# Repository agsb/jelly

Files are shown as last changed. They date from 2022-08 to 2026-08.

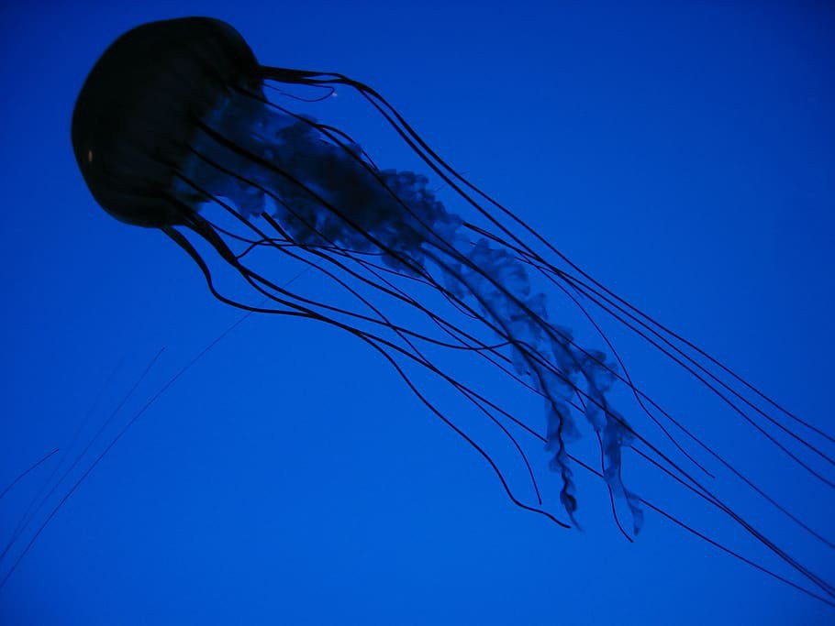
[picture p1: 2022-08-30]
jelly-blue.jpg

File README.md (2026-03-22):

-- THIS FILE IS A STUB ---

_01/05/2024 I'm on vacancy for refresh some ideas_

_22/03/2026 Review for make it_

# Jelly revision 2.0

Jelly is a concept, a alternative computer with a diferent paradigm, not for performance but for design.

Jelly is a minimal DIY 8-bit CPU made with CMOS chips, to perform computations using sequential access tapes.

## What is it ?

How make a new cpu without memory address, using only sequential access, for code, data and input/output ?

I want to learn about how old cpus are made by inside and understand about signals, gates, latches, pipelines, etc.

Jelly runs a minimal language, brainfunk, based in brainfuck, a minimal Turing-complete programming language with just eight commands. 

But Jelly includes few new commands to self.

Jelly uses sequential access to two ideal infinite tapes, first for code (aka ONE) and second for data (aka TWO). 

Any device could emulate a tape.

PS: 

The image is from https://en.freejpg.com.ar/free/info/100024149/jelly-fish-blue-water-background-sea-ocean-animal

I know that it will be slow.

Some notes are keeped at [ logbook ](https://github.com/agsb/jelly/blob/main/documents/LogBook.md).

There are a hackday log [ hackio ](https://hackaday.io/project/186689-jelly).

## Ideas

Jelly is not a common cpu.

- There is no general registers, just 3-state latches to keep the data bus safe. 

- There is no arithmetic logical unit (ALU), just a memory with a table of unary "math" results for increment, decrement and copy a byte, and also used to decode opcodes. Could include clear, shift right, shift left, negation.

- There is no comparator, just a flag for when a byte is zero or not.

- Uses Havard architeture, with code and data in diferent tapes.

- There is no memory address, just tapes that moves forward or backward.

- The standart input and output are instant stream devices, not tapes. 

And Jelly executes a esoteric language.

## Brainfunk

Jelly is really, a finite state machine, running by lookup tables and executing a extended version of language brainfuck, called brainfunk, which could have more 8 commands.

Jelly does a classical Read-Eval-Print Loop, or REPL, over bytes received from a code tape. For each byte, use a lookup table to translate into a opcode and execute actions. 

Not all bytes are opcodes and mapped as NOP, do nothing instruction, to catch those and just advance the code tape.

#### Table of OP-CODES
| opcode | ascii | action | code set | name |
| --- | --- | --- | --- | --- |
| 1 | \> | forward a tape one step | brainfuck | forward |
| 2 | \< | backward a tape one step | brainfuck | backward |
| 3 | \+ | increase byte at tape | brainfuck | increase |
| 4 | \- | decrease byte at tape | brainfuck | decrease |
| 5 | \. | output byte from tape | brainfuck | putchar |
| 6 | \, | input byte into tape | brainfuck | getchar |
| 7 | \[ | while loop  | brainfuck | while |
| 8 | \] | until loop  | brainfuck | until |
| 9 | \! | mark end of code | jelly | halt |
| 0 | \= | do nothing | jelly | noop |

- Any other ascii value is just translated as (0x0) noop.
- Opcodes 10, 11, 12, 13, 14, 15 reserved and could change.

## Jelly extensions

Jelly includes: (list can grow)

  - a noop, to do nothing, and moves code tape one step, forward or backward;
  
  - a eof, to end of code and halt, to be a complete Turing Machine;

### Jelly ideas

How the standart devices could be changed ? 

Maybe using the bytes at first two positions of data tape, to select which port to use, as input and output, as like in many microcontrolers ?

The math could include opcodes, for clear, shifts, negation, and reverse a byte.

## About loops

There are some brainfuck computers, but almost with the loop instructions _while_ and _until_ (\[ and \]) replaced by pre-compiled jumps. 

Jelly does not allow pre-compiler tricks, then need a logic to deal with loops.

The _while_ and _until_ loops are like the concepts of any programming language, but used together.

The _while_ ends the loop when the actual data byte is zero, then advances to pass the corresponding _until_. 

The _until_ repeats the loop while the actual data byte is not zero, then must go back after the corresponding _while_.

The loops can be nested, using a counter that increase for begins and decrease for again, finishing the loop when counter is zero. As a 8-bit circuit, the maximum nested loops is 255;

## Circuit Layout

How the Jelly circuit connects is explained in [circuit design](documents/CircuitDesign.md)

### Logic Loops

How loops are implemented in Jelly is explained in [logic loops](documents/LogicLoop.md)

## Main frame

Jelly will be a wirewrap circuit -- work in progress

## Work Bench

Jelly logic circuits needs some tests -- work in progress

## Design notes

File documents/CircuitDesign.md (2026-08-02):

--this file is still a stub--

# Circuit Design

In a processing unit, opcodes define what to make and microcode how to make. Opcode names an abstract action and microcode controls signals and flow of information to execute actions.

Jelly is a simple 8-bit digital circuit, all math, opcodes and microcodes are done by eeproms and latches. It haves a zero detector, a binary counter e some glue state logics, and LEDs many LEDS ! 

Jelly circuit include the interface for Device Control Circuit (DCC), that could be real tape or memory emulated.

Jelly uses 2kb space, address are A0-A10, data inputs are D0-D7, data outputs are Q0-Q7, and control lines are C0-C7. 

All chips used are CMOS, have /OE (output enable), CK (clock pulse) or CS (chip select), CR (clear latch) lines for select action. The eeproms have /WR (write enable) to VCC.

There are four 8-bit devices, a code tape, a data tape, a standart input and a standart output. For easy, a code_byte is read from code tape and data_byte is writed into or read from data tape. The standart devices are like streams and instantaneous.

The processing steps are based in lookup tables, defined by 16 (4-bits) operation codes - opcodes, each with 8 (3-bits) sequential steps - microcodes, in 4 (2-bits) modes, in total of 9 bits, 512 possibilities.

## Circuits

Rules:

- The chips are grouped by type, sequential numbers are used for identify;
- Use an internal and an external data bus;
- Minimize number of signals;
- Use pull-down to GND; 
- _"keep it simple, sweet"_;

### BOM

### States

02 eeproms, U1 and U2, are AT28C16, 150 ns (~ 6.7 MHz), 2k x 8-bits, and have /OE to GND, /CS to GND, /WR to VCC; U3 is reserved to an EEPROM future extention; Could be a AT28C64.

02 input latch, U4 and U5, 74HC574, 40 ns (< 20.0 MHz), octal D-Flip-Flop, 3-state, with clock (CK) and enable (/OE);

01 output latch, U6, 74HC574, 40 ns (< 20.0 MHz), octal D-Flip-Flop, 3-state, with clock (CK) and enable (/OE);

01 input-output switch, U7, is 74HC245, 40 ns (< 20.0 MHz), octal bi-diretional switch, 3-state, with direction (DIR) and enable (/OE);

01 binary counter, U8, 74HC393, (< 100 MHz), dual 4-bit binary counter, with clock (CK) and clear (CR);

### Glues

01 D-flip-flop, U10, is 74HC74, dual D-Type flip-flops, with clear and preset;

02 NAND gates, U15, U16, are 74HC00, 150 ns ( ~6.7 MHz ), quad 2-input NAND gate;

### Clock Circuit

One oscilator circuit with a 555, or 74HC00 and a crystal, gives a primary clock pulses less than 2.0 MHz; 

## Finite State Machine 

A binary up-counter 74HC393, U8, takes clock pulses from clock circuit, gives Q0-Q2 as A0-A3 into U1 (and U3), clear is CR3 and second counter _Q4-Q7 unused_;

A latch 74HC574, U4, takes D0-D7 from data bus, gives Q0-Q3 as A4-A7 into U1 (and U3), clock is CK4 and high nibble _Q4-Q7 unused_;

The eeprom(s) AT28C16, U1 (and U3), takes Q0-Q3 from U8 as A0-A3 and Q0-Q3 from U4 as A4-A7, U1 gives C0-C7 (and U3 gives C8-C15), as control lines to circuits, C0-C3 are T0-T3 and C4-C7 are M0-M3. 

This circuit is used to translate a byte as finite state machine (FSM) steps. 

It is used for opcode and microcode lookup, address A0-A2 are used for up 8 steps micro-code, A3-A6 for define 16 op-code, A7 selected by zero circuit detector, A8 selected by toggle a flip-flop as mode default or loop, _A9-A10 are reserved, not used_.

The lines D0-D7 (D8-D15) are used to select math operations and control signals inside and outside Jelly.

### Math Lookups and Decoder

One latch 74HC574, U5, takes D0-D7 from data bus, gives Q0-Q7 as A0-A7 into U2, clock is CK5;

One eeprom At28C16, U2, takes Q0-Q7 from U5 into A0-A7, takes C4-C6 from U1 into A8-A10, and gives Q0-Q7 into U6 as D0-D7; 

One latch 74HC574, U6, takes Q0-Q7 from U2 into D0-D7, giving Q0-Q7 as D0-D7 into data bus, output enable is /OE6, clock is CK6; 

The lookup table maps decode and unary operations as pages of 256 bytes, it could do more than increase and decrease. 

#### Table 1, Lookup M3 == 1
| name | M2 | M1 | M0 | action |
| ---- | ----- | ----- | ---- | --- |
| code | 0 | 0 | 0 | decode byte | 
| incr | 0 | 0 | 1 | increase |
| decr | 0 | 1 | 0 | decrease |
| copy | 0 | 1 | 1 | copy byte |
| | | | | |
| not  | 1 | 0 | 0 | one complement |
| lsh  | 1 | 0 | 1 | shift left 1 bit |
| rsh  | 1 | 1 | 0 | shift right 1 bit |
| copy | 1 | 1 | 1 | reverse bits |

Notes:
  - In _code_ all bytes are translated in valid opcodes range, 0 to 15, not defined symbols are mapped as noop; 
  - the code and copy are internal FSM operations, not allow from opcodes.
  - yes, was more 4 possible math: one complement, shift left, shift right, reverse. 

### External Devices

All devices are external and accessed by a 16 pin connector, with VCC, VSS, REQ, ACK, T0-T3 and D0-D7 data lines. 

( make it better !)

#### Table 2, Connector external
| line | Pin | Pin | line |
| --- | --- | --- | --- |
| ACK |  1 | 16 | VCC |
| D0  |  2 | 15 | T3 |
| D1  |  3 | 14 | T2 |
| D2  |  4 | 13 | T1 |
| D3  |  5 | 12 | T0 |
| D4  |  6 | 11 | D7 |
| D5  |  7 | 10 | D6 |
| GND |  8 |  9 | CLK |

The high nible T0-T1 selects devices, operations, comands and information for a controler at external word.

One input-output switch 74HC245, U7, takes Q0-Q7 from U6 into D0-D7, giving Q0-Q7 as D0-D7 into an external data bus, output enable is /OE7, direction is DR7; The Mode Operation is defined by 
T0-T3 from Finite State EEPROM U1

### Control Devices

The FSM eeproms gives Q0-Q7 (D8-Q15 with U3) for math and control lines. 

In the list of combinations used to control lines, state of devices and operations, the high nibble of U3.C4-C7 as T0-T3, vary from 0x1 to 0xD, leaving 0x0 to do nothing, and 0xE-0xF for select some extra states. 

Those extra states with some glue logics make needs just one eeprom as finite state machine. 

# ZZZZZ wip 

#### Table 3, Signals and states
| signal | combines | gives |
| -- | -- | -- |
| _used for control input/output transit_ | |
| U1.C0 | U4.CS | chip select line of U4 |
| U1.C1 | U5.CS | chip select line of U5 |
| U1.C2 | U6.OE | output enable line of U6 |
| U1.C3 | U7.OE | output enable line of U7 |
| _used for math unary operations and decode_ | |
| U1.C4 | U2.A8 | address line of U2 |
| U1.C5 | U2.A9 | address line of U2 |
| U1.C6 | U2.A10 | address line of U2 |
| U1.C7 | U6.CS | chip select line of U6 |
| _used to control devices_ | |
| U3.C0 | T0 | to connector device |
| U3.C1 | T1 | to connector device |
| U3.C2 | T2 | to connector device |
| U3.C3 | T3 | to connector device |
| _used to selects_ | | 
| U3.C4 | ??? | toggles MOVE line |
| U3.C5 | U1.A7 | toggles ZERO line |
| U3.C6 | U1.A8 | toggles MODE line |
| U3.C7 | ??? | clear D-flip-flop |
| halt | reduce AND clock | halt the clock |
| _used to detect zero value in data byte_ | | |
| zero | diode logic for D0 OR D1 OR D2 OR D3 OR D4 OR D5 OR D6 OR D7 | high when not zero |
| _extra connections toggles_ | | |
| | | |

Notes:

  - Zero detector could be done with diode logic OR for a Zero line.
  - Zero line is connected as U1.A7
  - Mode line is connected as U1.A8, 

--- need review ---

#### Table 4, Valid Controls
| byte | T3 | T2 | T1 | T0 || OE7 M3 | OE6 M2 | CS5 M1 | CS4 M0 | action |
| ---- | -- | -- | -- | --- |-- | --- | --- | --- | --- | --- |
| 0x00 | 0 | 0 | 0 | 0 || 0 | 0 | 0 | 0 | no action |
|  |  |  |  |  ||  |  |  |  |  |
| 0x60 | 0 | 1 | 1 | 0 || 0 | 0 | 0 | 0 | tape one, forward, no transfer |
| 0xA0 | 1 | 0 | 1 | 0 || 0 | 0 | 0 | 0 | tape two, forward, no transfer |
| 0x70 | 0 | 1 | 1 | 1 || 0 | 0 | 0 | 0 | tape one, backward, no transfer |
| 0xB0 | 1 | 0 | 1 | 1 || 0 | 0 | 0 | 0 | tape two, backward, no transfer |
|  |  |  |  |  ||  |  |  |  |  |
| 0x4C | 0 | 1 | 0 | 1 || 1 | 0 | 1 | 0 | tape one, write, U6 into U7 * |
| 0x8C | 1 | 0 | 0 | 1 || 1 | 0 | 1 | 0 | tape two, write, U6 into U7 |
| 0xCC | 1 | 1 | 0 | 1 || 1 | 0 | 1 | 0 | standard, write, U6 into U7 |
|  |  |  |  |  |  ||  |  |  |  |
| 0x5A | 0 | 1 | 0 | 0 || 1 | 1 | 0 | 0 | tape one, read, U7 into U5 |
| 0x9A | 1 | 0 | 0 | 0 || 1 | 1 | 0 | 0 | tape two, read, U7 into U5 |
| 0xDA | 1 | 1 | 0 | 0 || 1 | 1 | 0 | 0 | standard, read, U7 into U5 |
|  | |  |  |  |  ||  |  |  |  |
| 0x06 | 0 | 0 | 0 | 0 || 0 | 1 | 1 | 0 | none, none, U6 into U5 |
| 0x02 | 0 | 0 | 0 | 0 || 0 | 0 | 1 | 0 | none, none, clear U5, clear U3 **|
|  | |  |  |  |  |  ||  |  |  |
| 0x05 | 0 | 0 | 0 | 0 || 0 | 1 | 0 | 1 | none, none, U6 into U4, clear U3 |
| 0x01 | 0 | 0 | 0 | 0 || 0 | 0 | 0 | 1 | none, none, clear U4, clear U3 |
|  | |  |  |  ||  |  |  |  |  |

Notes:

- logics for /OE6 and /OE7 are inverted, just add a NOT later;  
- case 0x4C, tape one is code, no write allowed, never;
- case 0x02, set data latch to zero to be used as counter;
- case 0x05 and 0x01, also clear/reset U3;
- data bus D0-D7 have pull-down resistors for clear U4 and U5 when U6 and U7 are in 3-state.
- codes 0xFE, std forward, and 0xFF, std backward, do not exists and are used to control logic
- any other combination is invalid.

### Devices 

The lines U3.Q0-Q3 as T0-T3, output only and selects devices, operations, comands and information for a device controler at external word. The lines D0-D7 are bi-diretional, defaults to output. All lines are as pull-down and high actived. 

One bi-direcional switch, U7, 74HC245, uses D0-D7 as A0-A7 from internal data bus, uses B0-B7 as D0-D7 to external device bus, /OE is /OE7, DIR is DIR7.

An optional external, One dual 2:4 decoder, U9, 74HC139, uses T0-T3 as A0-A3 from U1, giving Y0-Y3 and Y4-Y7, for external controler, the /OE is GND.

Note: The /OE7 line is controled by not(T0 or T1) and direction DIR7 by T2; ****

#### Table 5, devices
| T3 | T2 | selects |
| --- | --- | --- |
| 0 | 0 | none, no device |  
| 0 | 1 | one, code tape | 
| 1 | 0 | two, data tape | 
| 1 | 1 | standart device |

#### Table 6, operations
| T1 | T0 | selects |
| --- | --- | --- |
| 0 | 0 | write into | 
| 0 | 1 | read from | 
| 1 | 0 | forward step| 
| 1 | 1 | backward step | 

Note: 
- order is (MSB) T3-T2-T1-T0 (LSB), (MSB) C3-C2-C1-C0 (LSB) 
- The standart input and output devices does no moves forward or backward.

### Glue Logics

The Zero detector circuit uses two quad dual OR gate, U13 and U14. Does (D0 OR D1 OR D2 OR D3 OR D4 OR D5 OR D6 OR D7). Wherever, U13 are all used and U14 gives Y3 as A8 into U1 and U2 of Jelly circuit, _spare one gate of U14_;

The Math selector circuit, uses one quad dual AND gates, U15. Does (M3 AND M0), (M3 AND M1), (M3 AND M2), gives Y1-Y3 as A8-A10 into U3, _spare one gate of U15_; 

The Toggle circuit, uses one quad dual AND gates, U16. Does (/M3 AND M0), (/M3 AND M1), (/M3 AND M2), gives Y0-Y1 as CLK1-CLK2 of U10, Y2 is reserved, _spare one gate of U16_;  

The U10 receive Y0-Y1 as CLK1-CLK2 from U16 and gives Q1 as A9 into U1 and U2, and Q2 to reverse direction circuit; 

The Reverse direction circuit gets Q2 from U10 and T2-T3 from U1, does ((Q2 AND T3) XOR T2) to DIR7 and T2 at connector;

All NOT() and XOR() are done by NAND ports;

## Lines

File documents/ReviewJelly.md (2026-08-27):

_this file is still a stub_

# Review of inside Jelly

## Talks

    Jelly talks to a Device. The device is the gateway to external world.
    Device have two internal infinite tapes, one of code and one of data, 
    and also a standart system for input and output.

## Goods

    1. Need a zero byte detector, for assert end loops

    2. Need a move selector flip-flop, forward or backward;

    3. Need a mode selector flip-flop, code or loop;

    4. Need a reset step, for resume step counter;

    5. Only one active device: none, code, data, stream

    6. Only one active action: read, write, forward, backward

    7. Math table for: decode, increase, decrease, copy, ( not, shift left, shift rigth ) 

    8. Need define a REQ/ACK handshake for Jelly and External IO 

    9. How sense ACK, when toggle REQ, trace external protocol

## Finite State Machines

_"FSMs are procedural, while planning is declarative."_

_"Informally, a category is just a collection of things, along with a particular relationship between these things"_

About MC14500 https://www.youtube.com/watch?v=ioL9cbNx0O8&t=2s

## Low frequency clock

For tests Jelly needs a low frequency oscillator as clock. 
A oscillator with one gate of 74HC14, a resistor between input and output 
pins and a capacitor between input and ground (GND) have frequency by 
_Hz = 1.2 * 10^6 / RC_ and use another gate to filter. 
Use R from 10k to 4M, use C from 1n to 100u;
( Using C = 100nF and R=10K, Hz ~ 1200 Hz, and C = 10uF and R=10K, Hz ~ 1.2 Hz, so on. )

## Concise Protocol

Two lines REQ and ACK. 

### Four-Phase

Four-Phase Handshake (RZ - Return-to-Zero): A very common and robust approach where control lines return to their initial state after each transaction. It involves four distinct steps:

    Request (Req) Active: Sender prepares data, then activates the Req line.
    Data Accepted: Receiver reads data, then activates the Ack line.
    Request Inactive: Sender detects Ack and brings Req low.
    Acknowledge Inactive: Receiver brings Ack low, returning the system to an idle state.

| REQ | ACK | results |
| -- | -- | -- |
|  0  |  0  | void |
|  1  |  0  | request |
|  1  |  1  | response |
|  0  |  1  | clear req |
|  0  |  0  | clear ack |

### Request-Acknowledge

The Jelly implementation is slightly diferent, Jelly and Device.

| SEQ | REQ | ACK | results |
| -- | -- | -- | -- |
| 0 |  0  |  0  | void state |
| 1 |  1  |  0  | Jelly prepares control and data, then active REQ |
| 2 |  1  |  0  | Device sense REQ, read controls |
| 3 |  1  |  1  | Device process data, then active ACK |
| 4 |  1  |  1  | Jelly sense ACK, process data |
| 5 |  0  |  1  | Jelly deactive REQ |
| 6 |  0  |  0  | Device sense REQ and deactive the ACK |
| 7 |  0  |  0  | return to void state |

Use REQ and ACK as a XOR to pause and continue the clock before it goes to 393/163 chip
    
| REQ | ACK | CLK | action |
| --- | --- | --- | --- |
| 0 | 0 | flow | device ready|
| 1 | 0 | stop | made a request to device|
| 1 | 1 | flow | device responds to request |
| 0 | 1 | stop | wait device ready for next |

## Components

U1  AT28C16 (A0-A10, D0-D7, /CE, /OE, /WE)

U2  AT28C16 (A0-A10, D0-D7, /CE, /OE, /WE)

U3  AT28C16 (A0-A10, D0-D7, /CE, /OE, /WE)

U4  74HC574 (D0-D7, Q0-Q7, CL, /OE), input code

U5  74HC574 (D0-D7, Q0-Q7, CL, /OE), input data

U6  74HC574 (D0-D7, Q0-Q7, CL, /OE), output data

U7  74HC245 (A0-A7, B0-B7, DR, /OE), bidirectional, code and data

U8  74HC393 (QA1, QB1, QC1, QD1, CLR1, /CLK1, QA2, QB2, QC2, QD2, CLR2, /CLK2)

U10 74HC74  (CLR1, CLK1, D1, Q1, /Q1, /PRE1, CLR2, CLK2, D2, Q2, /Q2, /PRE2)

U11 74HC74  (CLR1, CLK1, D1, Q1, /Q1, /PRE1, CLR2, CLK2, D2, Q2, /Q2, /PRE2)

U12 74HC00  (A1, A2, Y1, A3, A4, Y2, A5, A6, Y3, A7, A8, Y4) 

U13 74HC00  (A1, A2, Y1, A3, A4, Y2, A5, A6, Y3, A7, A8, Y4) 

## Buses

DB, data bus, (D0, D1, D2, D3, D4, D5, D6, D7), pull down with 10k resistors

CT, control bus, U1.(C0, C1, C2, C3, C4, C5, C6, C7), U3.(C8, C9, C10, C11, C12, C13, C14. C15)

IO, connector bus, (ACK, REQ, D0-D7, C8-C11, VCC, VSS)

## control

| C8 | C9 | device |
| -- | -- | -- |
| 0 | 0 | none | 
| 0 | 1 | code tape |
| 1 | 0 | data tape |
| 1 | 1 | std device |

| C10 | C11 | select |
| -- | -- | -- |
| 0 | 0 | read |
| 0 | 1 | write |
| 1 | 0 | forward |
| 1 | 1 | backward |

| C8 | C9 | C10 | C11 |  action |
| -- | -- | -- | -- | -- |
| 0  | 0  | 0  | 0  | nothing |
| 0  | 0  | 0  | 1  | nothing |
| 0  | 0  | 1  | 0  | nothing |
| 0  | 0  | 1  | 1  | nothing |
| | | | | 
| 1  | 1  | 1  | 0  | reserved |
| 1  | 1  | 1  | 1  | reserved |
    
## Tables 

### controls 
    
| origin | named | destin | note |
| -- | -- | -- | -- |
| U1.D0  | C0 | U4.CK | clock must be pulsed low to high |
| U1.D1  | C1 | U5.CK | clock must be pulsed low to high |
| U1.D2  | C2 | U6.CK | clock must be pulsed low to high |
| U1.D3  | C3 | U6.OE | enable output U6, tied to U7.DIR |
| U1.D4  | C4 | U7.OE | enable output U7 |
| U1.D5  | C5 |  | reserved |
| U1.D6  | C6 |  | reserved |
| U1.D7  | C7 |  | reserved |
|  |  |  |  |
| U3.D0 | C8 | Connector | device |
| U3.D1 | C9 | Connector | device |
| U3.D2 | C10 | Connector | select |
| U3.D3 | C11 | Connector | select |
| U3.D4 | C12 | Connector | request |
| U3.D5 | C13 |  | reserved |
| U3.D6 | C14 |  | reserved |
| U3.D7 | C15 |  | reserved |

Note: 

        U6.OE  goes high when input from Device and 
            goes low when output into Device

        U7.DIR tied to U6.OE, when U6.OE low U7.DIR is low, direction
            is from port B into port A, then port B must be connected 
            to DB and port A to Connector.

        C8 and C9 tied to U2.OE
        
#### Tables

https://github.com/agsb/jelly/blob/main/documents/ReviewJellyTable.md

### Math 

When C8 and C9 are low, C10, C11 and C12 are math functions. 
C8 and C9 must be pulldown, and connected to U2.OE (need some glue circuit)
Connect U3.D2(C10) to U2.A8, U3.D3(C11) to A2.A9, U3.D4(C12) to U2.A10 to select math function

### Clock

1. CLOCK -> U8(D1)

### Code

1. DB(D0-D7) -> U4(D0-D7)

2. U8(QA1, QB1, QC1, QD1) -> U1(A0-A3), 16 steps or stages

3. U4(Q0-Q3) -> U1(A4-A7), 16 opcodes, (A8, A9, A10) 8 modes

4. U4(Q4-Q7) -> Not used

5. U1(D0-D7) -> CT(C0-C7)

### Data Internal 

6. DB(D0-D7) -> U5(D0-D7)

7. U5(Q0-Q7) -> U2(A0-A7)

8. CT(C10,C11,C12) -> U2(A8,A9), 8 math operations: none, INC, DEC, COPY, (NOT, SHL, SHR, 

9. CT(C8,C9) --> U2.OE

10. U2(D0-D7) -> U6(D0-D7)

11. U6(Q0-Q7) -> DB(D0-D7)

## Data External Output

11. DB(D0-D7) -> U7(B0-B7)

12. U7(B0-B7) -> U7(A0-A7), internal

13. U7(A0-A7) -> IO(D0-D7)

## Data External Input

14. IO(D0-D7) -> U7(A0-A7)

15. U7(A0-A7) -> U7(B0-B7), internal

16. U7(B0-B7) -> DB(D0-D7)

## Problems

When detect a ACK, it could be from a:

* read a byte from code tape
* write a byte into code tape ---- ERROR
* read a byte from data tape
* write a byte into data tape
* read a byte from stds 
* write a byte into stds
* move code tape forward
* move code tape backward
* move data tape forward
* move data tape backward

    On read cases, the byte must be load somewhere.
## Notes

The data bus D0-D7 is pull down 10k resistors. 
    
The addr bus A0-A7 is pull down 10k resistors. 

Using U4.CL, U5.CL and U6.CL tied to OE, pulsed to high do load the latch. 

Ever when U6.OE is low U7.DIR must goes to outside, 
        then port B is connected to DB and port A is connected to CON.

An 74HC14 serves the clock to 74HC393 steps.

The (T0 T1) the 0/0 is a internal, else is a external and tied REQ

using ANOTHER AT28C16 allow more controls.

## References

https://web.stanford.edu/class/archive/cs/cs103/cs103.1132/lectures/19/Small19.pdf

https://bailleux.net/pub/ob-project-gray1.pdf

https://www.gamedevs.org/uploads/three-states-plan-ai-of-fear.pdf

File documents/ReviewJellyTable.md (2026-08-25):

__This file is still a stub__

# Control Table

The lines from U1 and U3 gives the control signals to U4, U5, U6, U7 and to Connector to Device.

Notes:

    U6.OE6 tied U7.DIR
    When U6 is low active, then U7 direction is from port B to port A, byte into Connector.
    When U6 is high inactive, then U7 direction is from port A to port B, byte from Connector.

Using PinUnit for easy
    
| C0  | C1  | C2  | C3  | C4  | C5  | C6  | C7  | C8  | C9  | C10 | C11 | C12 | C13 | C14 | C15 | results | 
| --- | --- | --- | --- | --- | --- | --- | --- | --- | --- | --- | --- | --- | --- | --- | --- | --- |
| CK4 | CK5 | CK6 | OE6 | OE7 |  0  | 0 | 0 | DEV0 | DEV1 | SEL0 | SEL1 | REQ |  0 | 0 | 0 | 0 |  | 
| | | | | | | | | | | | | | | | |  |
| 0 | 0 | 0 | 0 | 0 | 0 | 0 | 0 | 0 | 0 | 0 | 0 | 0 | 0 | 0 | 0 |  | 
| 1 | 0 | 0 | 0 | 0 | 0 | 0 | 0 | 0 | 0 | 0 | 0 | 0 | 0 | 0 | 0 | load db byte to latch U4 | 
| 0 | 1 | 0 | 0 | 0 | 0 | 0 | 0 | 0 | 0 | 0 | 0 | 0 | 0 | 0 | 0 | load db byte to latch U5 | 
| 0 | 0 | 1 | 0 | 0 | 0 | 0 | 0 | 0 | 0 | 0 | 0 | 0 | 0 | 0 | 0 | load db byte to latch U6 | 
| 0 | 0 | 0 | 1 | 0 | 0 | 0 | 0 | 0 | 0 | 0 | 0 | 0 | 0 | 0 | 0 |  | 
| | | | | | | | | | | | | | | | |  |
| | | | | | | | | | | | | | | | |  |
| | | | | | | | | | | | | | | | |  |

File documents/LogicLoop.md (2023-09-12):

  
( this file is still a stub ) 

# Logic Loop

All Jelly opcodes are easy implemented except loops. 

A interpreter of brainfunk, in pseudo-code, _left not optimized, sure not optimized, did I said it is not optimized ?_ :

         // Notes:
         // getch(), putch() e halt() are external
         // for easy the tapes are mapped as sequential memory
         
         char * code_ptr = POINTER_TO_CODE;
         char * data_ptr = POINTER_TO_DATA;
         
         int mode = 0; // the page
         int move = 0; // the direction
         int data_byte = 0;
         int code_byte = 0;
         
         do {
             code_byte = *code_ptr;
             
             // end of loop ?
             if (code_byte == '\[' and data_byte == 0) mode = 1, move = 0;
             // not end of loop ?
             if (code_byte == '\]' and data_byte != 0) mode = 1, move = 1;
            
             if (mode == 1) { 
                 data_byte = 0; // used as counter
                 do {
                     code_byte = *code_ptr;
                     if (code_byte == '\[') data_byte++;
                     if (code_byte == '\]') data_byte--;
                     if (move == 0) code_ptr++;
                     if (move == 1) code_ptr--;
                 } while (data_byte != 0);
                 // 
                 if (move == 1) code_ptr++, code_ptr++;
                 mode = 0;
                 move = 0;
                 data_byte = *data_ptr;
                 continue;
             }
             
             // mode 0 == 0, all other opcodes: < > . , + -
             
             if (code_byte == '+') { data_byte = *data_ptr; data_byte++; *data_ptr = data_byte; }
             if (code_byte == '-') { data_byte = *data_ptr; data_byte--; *data_ptr = data_byte; }
             if (code_byte == '>') { data_ptr++; }
             if (code_byte == '<') { data_ptr--; }
             if (code_byte == '.') { data_byte = *data_ptr; putch(data_byte); }
             if (code_byte == ',') { data_byte = getch(); *data_ptr = data_byte; }

             if (code_byte == '!') { halt(); }
             code_ptr++;
           } while (1);

Notes:

For easy, the \[ is called _while_ and the \] is called _until_
                    
When grouping the code in dependence of state of loop, gives two modes, the normal mode does all opcodes but _while_ and _until_. Those are executed by the loop mode, described as: 

When a _while_ occurs and the data byte is zero, it's the end of the loop, so it must step **forward** to find the corresponding _until_, and return to mode normal;

When a _until_ occurs and the data byte is not zero, then it is not the end of the loop, so it must step **backward** to find the corresponding _while_, and return to mode normal;

Since no data bytes are read in loop mode, the circuit U5-U2-U6 is used as a counter for up to 255 nested loops;

### Actions 

the actions from pseudo-code are:

- move code tape forward
- move code tape backward
- move data tape forward
- move data tape backward
- read from data tape into data latch
- increase data latch
- decrease data latch
- write from data latch into data tape
- read from code tape into data latch
- decode data latch
- copy from data latch to code latch
- clear data latch
- read from standart input device into data latch
- write from data latch into standart output device
- test if a data latch is zero

Those actions must be done by combination of control lines, selects which chips is active at a clock instant.

## How To

How implement the loop opcodes _while_ and _until_ , keep me in a round-robin by months without a feasible solution.

A solution is a true table of five state lines, while, again, zero, mode, move and two result toggle switches S1 and S2, that controls which mode and reverse movement.

the solution was make true-table for lines and states.

- _while_ is a condition set high when code_byte is [

- _until_ is a condition set high when code_byte is ]

- _zero_ is a condition set low when data_byte is zero. 

- _mode_ is condition a address line for eeproms U1 and U3.

- _move_ is condition a address line for reverse movement.

- switch mode is the next state of _mode_.

- switch move is the next state of _move_.

## True Table

   | case | zero | mode | move | _while_ | _again_ | _switch mode_ | _switch move_ | results |
   | --- | --- | --- | --- | --- | --- | --- | --- | --- | 
   | 1 | 0/1 | 0 | 0 | 0 | 0 | 0 | 0 | default |
   | 2 | 0 | 0 | 0 | 1 | 0 | 1 | 0 | set mode,  |
   | 3 | 1 | 0 | 0 | 0 | 1 | 1 | 1 | set mode, set move |
   | 4 | 0 | 1 | 0/1 | 0 | 0 | 0 | 0 | set mode, set move | 
   | 5 | 1 | 1 | 0/1 | 1 | 0 | 1 | 0/1 | increase counter, set mode, set move |
   | 6 | 1 | 1 | 0/1 | 0 | 1 | 1 | 0/1 | decrease counter, set mode, set move |

The paging is controled just from five conditions, and _switch mode_ and _switch move_ could do clock lines to D-flip-flops.

For simplify, when mode is normal (0), move is always for forward (0) and when mode is loop (1), the state of _while_ and _until_ does changes the counter;

## Circuits

Jelly have 16 opcodes of 8 microcodes, then a code page uses 128 bytes.

I tried to implement the truth table in three ways: 1. With only one FSM eeprom and complex multiplex circuits for logics; 2. With 4 pages at second FSM eeprom and external circuits; and 3. With 6 pages at second FSM eeprom and few external circuits;

### one eeprom and many circuits

### two eeproms and less circuits

### two eeproms and minimal logic circuits

## Considerations

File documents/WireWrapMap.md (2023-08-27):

# WireWrapMap

-- This file is still a stub --

## Chips used in Jelly

  - U1 AT28C16 [at28c16](https://github.com/agsb/jelly/assets/14941647/0e6a42e7-9d13-4c5b-8078-834cc9717078)
  - U2 AT28C16 [at28c16](https://github.com/agsb/jelly/assets/14941647/0e6a42e7-9d13-4c5b-8078-834cc9717078)
  - U3 AT28C26 [at28c16](https://github.com/agsb/jelly/assets/14941647/0e6a42e7-9d13-4c5b-8078-834cc9717078)
  - U4 74HC574 [74hc574](https://github.com/agsb/jelly/assets/14941647/389d5967-7fb1-4645-8b06-98f8ca35686f)
  - U5 74HC574 [74hc574](https://github.com/agsb/jelly/assets/14941647/389d5967-7fb1-4645-8b06-98f8ca35686f)
  - U6 74HC574 [74hc574](https://github.com/agsb/jelly/assets/14941647/389d5967-7fb1-4645-8b06-98f8ca35686f)
  - U7 74HC245 [74hc245](https://github.com/agsb/jelly/assets/14941647/2990746c-01e9-4c97-b71f-3ceca05f751b)
  - U8 74HC393 [74hc393](https://github.com/agsb/jelly/assets/14941647/131a82d1-9269-4ded-93cc-4d0f6053b101)
  - U9  74HC74 [74hc74](https://github.com/agsb/jelly/assets/14941647/7b43e177-1a82-49fd-ad0a-cf376e5011dd)
  - U10 74HC00 [74hc00](https://github.com/agsb/jelly/assets/14941647/2f70cb16-b870-4e8b-bac9-e86a2bcbbb6e)
  - C1 to C10, capacitor 100nF
  - C11 to C14, capacitor 4.7uF 

## Connections for WireWrap

  - POWER, all VCC connect U1.24, U2.24, U3.24, U4.20, U5.20, U6.20, U7.20, U8.14, U9.14, U10.14
  - GROUND, all GND connect U1.12, U2.12, U3.12, U4.10, U5.10, U6.10, U7.10, U8.7, U9.7, U10.7
  - CAPS, (U1.24-C1.1, C1.2-U1.12) for U1 C1 to U10 C10

#### 
	// master FSM eeprom
	U1.01-ZERO
	U1.02-U4.16
	U1.03-U4.17
	U1.04-U4.18
	U1.05-U4.19
	U1.06-U8.11
	U1.07-U8.10
	U1.08-U8.09
	U1.09-U4.11	// CLK
	U1.10-U5.11	// CLK
	U1.11-U6.11	// CLK
	U1.12-GND
	U1.13-U6.01	// /OE
	U1.14-U7.01	// /OE
	U1.15-U2.A8
	U1.16-U2.A9
	U1.17-U2.A10
	U1.18-GND
	U1.19-GND	// A10
	U1.20-GND
	U1.21-VCC
	U1.22-A9 ????
	U1.23-A8 ????
	U1.24-VCC

	// master Math/Decode eeprom
	U2.01-U5.12
	U2.02-U5.13
	U2.03-U5.14
	U2.04-U5.15
	U2.05-U5.16
	U2.06-U5.17
	U2.07-U5.18
	U2.08-U5.19
	U2.09-U6.02
	U2.10-U6.03
	U2.11-U6.04
	U2.12-GND
	U2.13-U6.05
	U2.14-U6.06
	U2.15-U6.07
	U2.16-U6.08
	U2.17-U6.09
	U2.18-GND
	U2.19-A10 ???
	U2.20-GND
	U2.21-VCC
	U2.22-A9 ???
	U2.23-A8 ???
	U2.24-VCC

	// control FSM eeprom
	U3.01-ZERO
	U3.02-U1.02
	U3.03-U1.03
	U3.04-U1.04
	U3.05-U1.05
	U3.06-U1.06
	U3.07-U1.07
	U3.08-U1.08
	U3.09-
	U3.10-
	U3.11-
	U3.12-GND
	U3.13-
	U3.14-
	U3.15-
	U3.16-
	U3.17-
	U3.18-GND
	U3.19-U1.19
	U3.20-GND
	U3.21-VCC
	U3.22-U1.22
	U3.23-U1.23
	U3.24-VCC
	
	// code byte latch, only low nibble used
	U4.01-GND
	U4.02-U5.02
	U4.03-U5.03
	U4.04-U5.04
	U4.05-U5.05
	U4.06-U5.06
	U4.07-U5.07
	U4.08-U5.08
	U4.09-U5.09
	U4.10-GND
	U4.11-CLK ????
	U4.12-NC
	U4.13-NC
	U4.14-NC
	U4.15-NC
	U4.16-U1.02
	U4.17-U1.03
	U4.18-U1.04
	U4.19-U1.05
	U4.20-VCC

	// data byte latch, input into Math
	U5.01-GND
	U5.02-U6.19
	U5.03-U6.18
	U5.04-U6.17
	U5.05-U6.16
	U5.06-U6.15
	U5.07-U6.14
	U5.08-U6.13
	U5.09-U6.12
	U5.10-GND
	U5.11-CLK ????
	U5.12-U2.01
	U5.13-U2.02
	U5.14-U2.03
	U5.15-U2.04
	U5.16-U2.05
	U5.17-U2.06
	U5.18-U2.07
	U5.19-U2.08
	U5.20-VCC

	// data byte latch, output from Math
	U6.01-????
	U6.02-U2.19
	U6.03-U2.18
	U6.04-U2.17
	U6.05-U2.16
	U6.06-U2.15
	U6.07-U2.14
	U6.08-U2.13
	U6.09-U2.12
	U6.10-GND
	U6.11-CLK ????
	U6.12-U7.09
	U6.13-U7.08
	U6.14-U7.07
	U6.15-U7.06
	U6.16-U7.05
	U6.17-U7.04
	U6.18-U7.03
	U6.19-U7.02
	U6.20-VCC

	// input output switch
	U7.01-DIR ???
	U7.02-U6.19
	U7.03-U6.18
	U7.04-U6.17
	U7.05-U6.16
	U7.06-U6.15
	U7.07-U6.14
	U7.08-U6.13
	U7.09-U6.12
	U7.10-GND
	U7.11-CONN9
	U7.12-CONN8
	U7.13-CONN6
	U7.14-CONN5
	U7.15-CONN4
	U7.16-CONN3
	U7.17-CONN2
	U7.18-CONN1
	U7.19-OE ????
	U7.20-VCC

	U8.12-U8.08	// counts 0 to 7 and resets.
	U8.13-?????	// whats comes to clear it

	NC-U8.01
	NC-U8.02
	NC-U8.03
	NC-U8.04
	NC-U8.05
	NC-U8.06

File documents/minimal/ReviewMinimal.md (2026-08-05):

_this file is still a stub_

# review of inside a really minimal Jelly

## goods

    1. Need a zero byte detector, for assert end loops

    2. Need a move selector flip-flop, forward or backward;

    3. Need a mode selector flip-flop, code or loop;

    4. Need a reset step, for resume step counter;

    5. Only one active device: none, code, data, stream

    6. Only one active action: read, write, forward, backward

    7. Math table for: decode, increase, decrease, copy, zero(?) 

    8. Need define a REQ/ACK handshake for Jelly and External IO, how sense ACK, when toggle REQ, trace external protocol

## Finite State Machines

_"FSMs are procedural, while planning is declarative."_

_"Informally, a category is just a collection of things, along with a particular relationship between these things"_

## low frequency clock

For tests Jelly needs a low frequency oscilator as clock. A oscilator with one gate of 74HC14, a resistor between input and output pins and a capacitor between input and ground (GND) have frequency by _Hz = 1.2 * 10^6 / RC_ and use another gate to filter. 
Use R from 10k to 4M, use C from 1n to 100u;
( Using C = 100nF and R=10K, Hz ~ 1200 Hz, and C = 10uF and R=10K, Hz ~ 1.2 Hz, so on. )

## Consise Protocol

Two lines REQ and ACK. 

### Four-Phase

Four-Phase Handshake (RZ - Return-to-Zero): A very common and robust approach where control lines return to their initial state after each transaction. It involves four distinct steps:

    Request (Req) Active: Sender prepares data, then activates the Req line.
    Data Accepted: Receiver reads data, then activates the Ack line.
    Request Inactive: Sender detects Ack and brings Req low.
    Acknowledge Inactive: Receiver brings Ack low, returning the system to an idle state.

| REQ | ACK | results |
|  0  |  0  | void |
|  1  |  0  | request |
|  1  |  1  | response |
|  0  |  1  | clear req |
|  0  |  0  | clear ack |

### Request-Acknowledge

When a request is made with (T0 T1 T2 T3):

    1. Place a request 
    2. Down ACK
    3. Wait REQ Down
    4. Resume request
    5. Up ACK
    6. wait REQ UP

## Components

U1  AT28C16 or AT28C32 (A0-A12, D0-D7, /CE, /OE, /WE)

U2  AT28C16 or AT28C32 (A0-A12, D0-D7, /CE, /OE, /WE)

U3  AT28C16 or AT28C32 (A0-A12, D0-D7, /CE, /OE, /WE) ***

U4  74HC574 (D0-D7, Q0-Q7, CL, /OE), input code

U5  74HC574 (D0-D7, Q0-Q7, CL, /OE), input data

U6  74HC574 (D0-D7, Q0-Q7, CL, /OE), output data

U7  74HC245 (A0-A7, B0-B7, DR, /OE), bidiretional, code and data

U8  74HC393 (QA1, QB1, QC1, QD1, CLR1, /CLK1, QA2, QB2, QC2, QD2, CLR2, /CLK2)

U10 74HC74  (CLR1, CLK1, D1, Q1, /Q1, /PRE1, CLR2, CLK2, D2, Q2, /Q2, /PRE2)

U11 74HC00  (A1, A2, Y1, A3, A4, Y2, A5, A6, Y3, A7, A8, Y4) 

## Buses

DB, data bus, (D0, D1, D2, D3, D4, D5, D6, D7)

CT, control bus, (C0, C1, C2, C3, C4, C5, C6, C7)

IO, conector bus, (CLK, ACK, D0-D7, T0-T3)

## IO Control

    | T3 | T2 | device OR |
    | 0 | 0 | none | 
    | 0 | 1 | code tape |
    | 1 | 0 | data tape |
    | 1 | 1 | std device |

    | T1 | T0 | select OR |
    | 0 | 0 | read |
    | 0 | 1 | write |
    | 1 | 0 | forward |
    | 1 | 1 | backward |

    | T3 | T2 | T1 | T0 | not used |
    | 0  | 0  | 0  | 0  | nothing |
    | 0  | 0  | 0  | 1  | nothing |
    | 0  | 0  | 1  | 0  | nothing |
    | 0  | 0  | 1  | 1  | nothing |
    | | | | | 
    | 1  | 1  | 1  | 0  | clear ACK |
    | 1  | 1  | 1  | 1  | nothing |

## Tables 

### controls 
    
U1(D0-D7) to (U4.CE, U5.CE, U6.CE, U6.OE, U7.DIR, U7.OE, X6, X7). Note that U4.OE and U5.OE are always low, because U4-U1 and U5-U2 are closed circuits.

### functions

U3(D0-D7) to (M0, M1, M2, M3, T0, T1, T2, T3)

### Clock

1. CLOCK -> U8(D1)

### Code

1. U8(QA1, QB1, QC1) -> U1(A0, A1, A2), 8 steps or stages

1. DB(D0-D7) -> U4(D0-D7)

2. U4(Q0-Q4) -> U1(A3-A7), 32 opcodes, (A8, A9, A10) 8 modes

3. U1(D0-D7) -> CT(C0-C7)

### Data Internal 

4. DB(D0-D7) -> U5(D0-D7)

5. U5(Q0-Q7) -> U2(A0-A7)

6. CT(C0,C2,C3) -> U2(A8,A9,A10)

6. U2(D0-D7) -> U6(D0-D7)

7. U6(Q0-Q7) -> DB(D0-D7)

## Data External 

10. DB(D0-D7) -> U7(A0-A7)

11. U7(B0-B7) -> IO(D0-D7)

10. IO(D0-D7) -> U7(B0-B7)

11. U7(A0-A7) -> DB(D0-D7)

## Notes

    The data bus D0-D7 is pull down 10k resistors. 
    Using U4.CL or U5.CL pulse with U6.OE high and U7.OE high,
    loads zero. 

    An 74HC14 serves the clock to 74HC393 steps.

## References

https://web.stanford.edu/class/archive/cs/cs103/cs103.1132/lectures/19/Small19.pdf

https://bailleux.net/pub/ob-project-gray1.pdf

https://www.gamedevs.org/uploads/three-states-plan-ai-of-fear.pdf

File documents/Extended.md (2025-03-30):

# Extended

An Extended Brainfunk was proposed [1] to simulating digital conditions 
for complex systems. 

## code 

A virtual infinite tape with two heads (0 and 1), 
one head is a program cursor and other is a data cursor, and keep same 
operations but change . and , to exchange bytes between heads and two 
more { and } for move the other head backward and forward.

```
    < head0 = head0 - 1
    > head0 = head0 + 1
    { head1 = head1 - 1
    } head1 = head1 + 1
    - tape[head0] = tape[head0] - 1
    + tape[head0] = tape[head0] + 1
    . tape[head1] = tape[head0]
    , tape[head0] = tape[head1]
    [ if (tape[head0] == 0): jump forwards to matching ] command.
    ] if (tape[head0] != 0): jump backwards to matching [ command.

```

## extras

## references

[1] "Computational Life: How Well-formed, Self-replicating Programs 
Emerge from Simple Interaction", 
Blaise Agüera y Arcas†, Jyrki Alakuijala†, James Evans‡,
Ben Laurie†, Alexander Mordvintsev†, Eyvind Niklasson†,
Ettore Randazzo†, Luca Versari†,
†Google, Paradigms of Intelligence Team and ‡The University of Chicago
{blaisea, jyrki, benl, moralex, eyvind, etr, veluca}@google.com
jevans@uchicago.ed

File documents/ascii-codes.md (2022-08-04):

--- this file is a stub ---

| Dec 	| Hex 	| Binary 	| HTML 	| Char 	| Description |
| --- | --- | --- | --- | --- | --- |
| 0 	| 00 	| 00000000 	| &#0; 	| NUL 	| Null |
| 1 	| 01 	| 00000001 	| &#1; 	| SOH 	| Start of Header |
| 2 	| 02 	| 00000010 	| &#2; 	| STX 	| Start of Text |
| 3 	| 03 	| 00000011 	| &#3; 	| ETX 	| End of Text |
| 4 	| 04 	| 00000100 	| &#4; 	| EOT 	| End of Transmission |
| 5 	| 05 	| 00000101 	| &#5; 	| ENQ 	| Enquiry |
| 6 	| 06 	| 00000110 	| &#6; 	| ACK 	| Acknowledge |
| 7 	| 07 	| 00000111 	| &#7; 	| BEL 	| Bell |
| 8 	| 08 	| 00001000 	| &#8; 	| BS 	| Backspace |
| 9 	| 09 	| 00001001 	| &#9; 	| HT 	| Horizontal Tab |
| 10 	| 0A 	| 00001010 	| &#10; 	| LF 	| Line Feed |
| 11 	| 0B 	| 00001011 	| &#11; 	| VT 	| Vertical Tab |
| 12 	| 0C 	| 00001100 	| &#12; 	| FF 	| Form Feed |
| 13 	| 0D 	| 00001101 	| &#13; 	| CR 	| Carriage Return |
| 14 	| 0E 	| 00001110 	| &#14; 	| SO 	| Shift Out |
| 15 	| 0F 	| 00001111 	| &#15; 	| SI 	| Shift In |

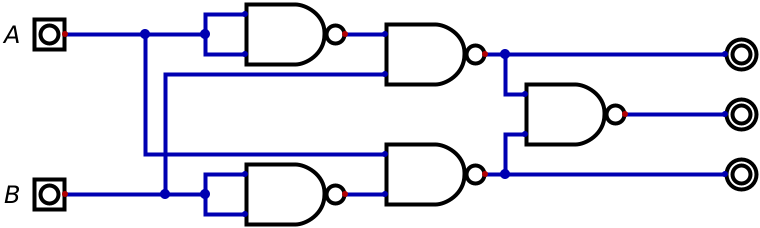
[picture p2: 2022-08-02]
jellys/extras/2bit-comparator.png

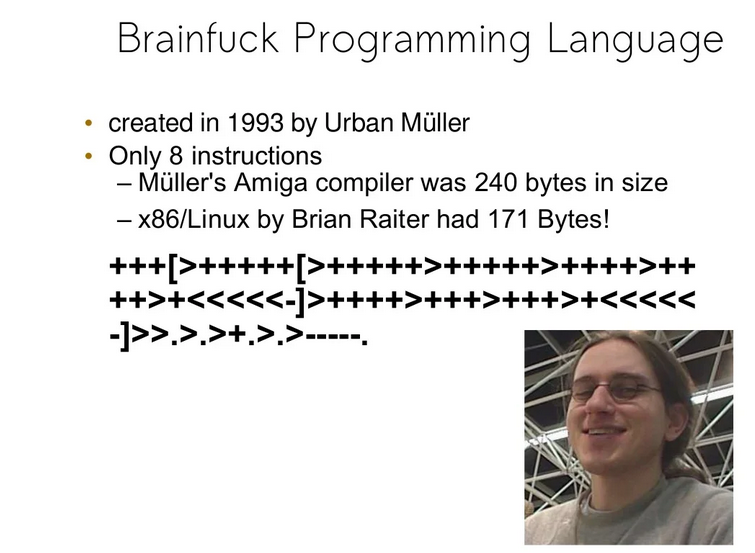
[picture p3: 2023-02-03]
documents/brainfuck-urban-muller.png

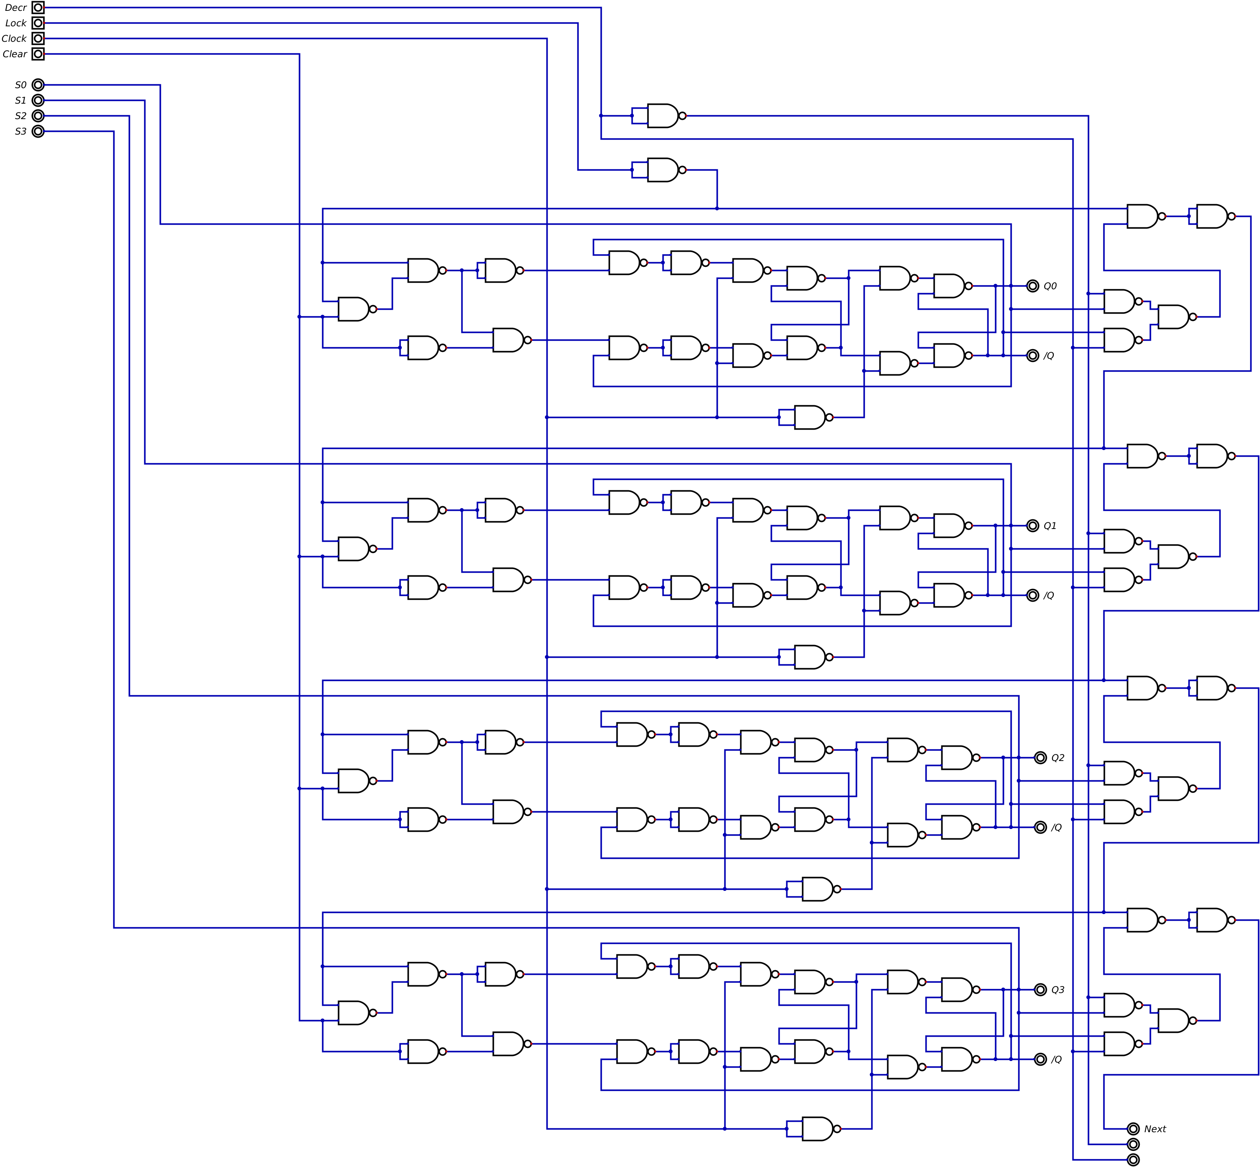
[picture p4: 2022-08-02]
jellys/extras/jk-counter-clr-inc-dec-4bits.png

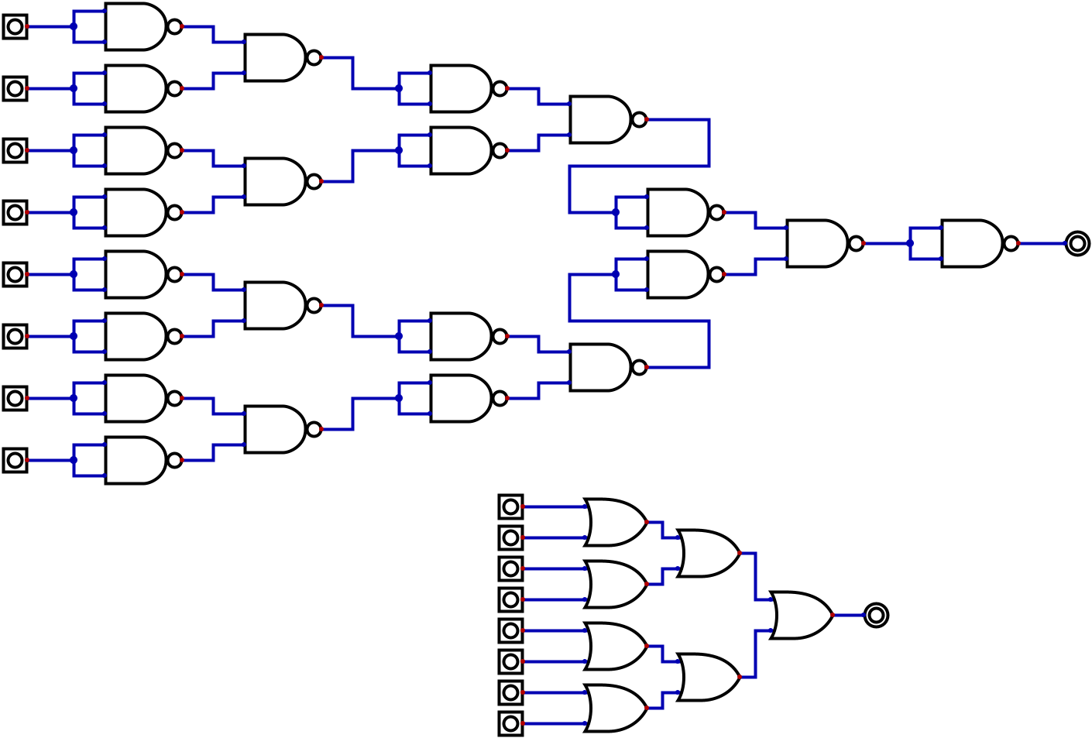
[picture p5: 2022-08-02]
jellys/extras/comparator-zero-8bits.png

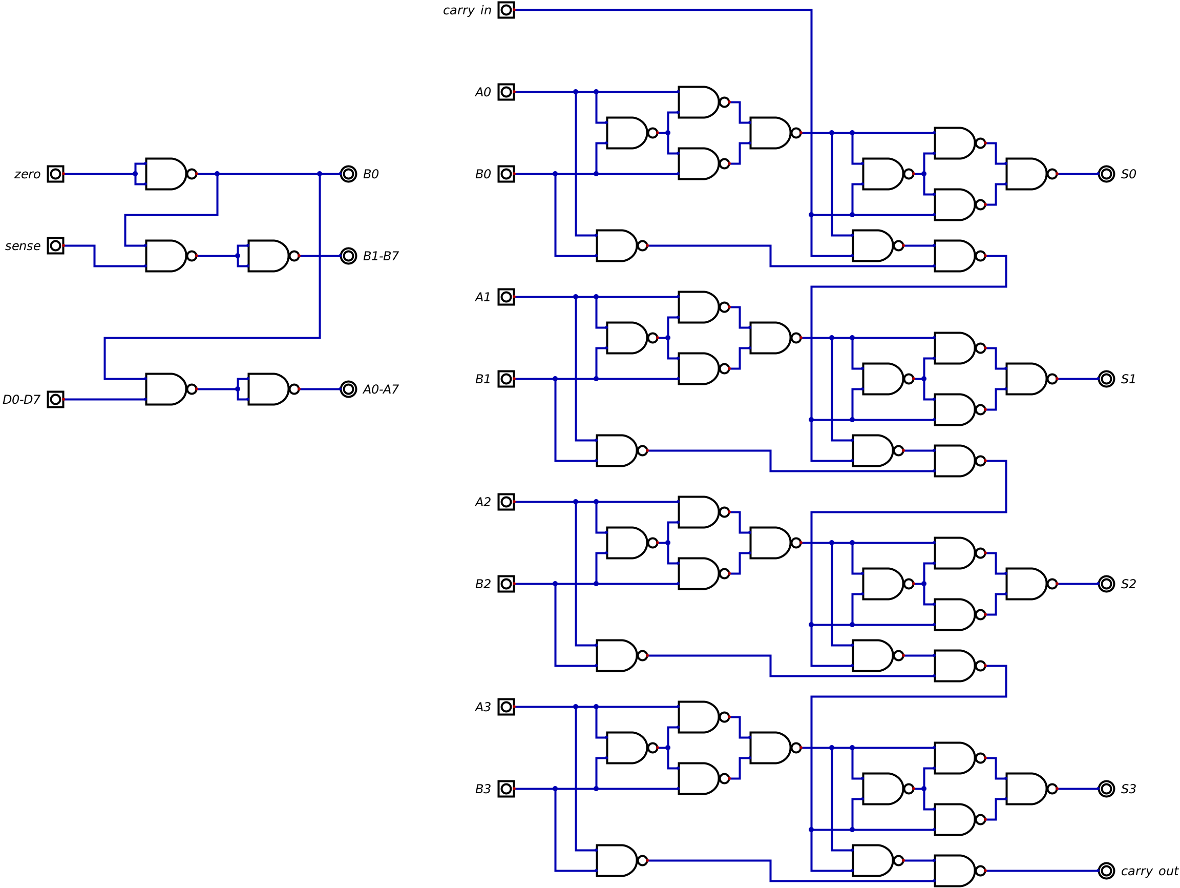
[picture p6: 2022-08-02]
jellys/extras/d-adder-inc-dec-4bits.png

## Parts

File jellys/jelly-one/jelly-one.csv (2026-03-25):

Source: | /home/agsb/Projects/jelly-one/jelly-one.kicad_sch
Date: | qui 04 ago 2022 15:55:19
Tool: | Eeschema 6.0.4-6f826c9f35~116~ubuntu18.04.1
Generator: | /usr/share/kicad/plugins/bom_csv_grouped_by_value.py
Component Count: | 10
Individual Components:
Item | Qty | Reference(s) | Value | LibPart | Footprint | Datasheet
 |  | U1 | 74AHC374 | 74xx:74AHC374 |  | https://assets.nexperia.com/documents/data-sheet/74AHC_AHCT374.pdf
 |  | U2 | 74LS32 | 74xx:74LS32 |  | http://www.ti.com/lit/gpn/sn74LS32
 |  | U3 | 74LS32 | 74xx:74LS32 |  | http://www.ti.com/lit/gpn/sn74LS32
 |  | U4 | 74LS32 | 74xx:74LS32 |  | http://www.ti.com/lit/gpn/sn74LS32
 |  | U5 | 74LS393 | 74xx:74LS393 |  | 74xx\74LS393.pdf
 |  | U6 | 74LS393 | 74xx:74LS393 |  | 74xx\74LS393.pdf
 |  | U7 | 74LS08 | 74xx:74LS08 |  | http://www.ti.com/lit/gpn/sn74LS08
 |  | U8 | 74LS32 | 74xx:74LS32 |  | http://www.ti.com/lit/gpn/sn74LS32
 |  | U9 | 74LS32 | 74xx:74LS32 |  | http://www.ti.com/lit/gpn/sn74LS32
 |  | U10 | 28C256 | Memory_EEPROM:28C256 |  | http://ww1.microchip.com/downloads/en/DeviceDoc/doc0006.pdf
Collated Components:
Item | Qty | Reference(s) | Value | LibPart | Footprint | Datasheet
1 | 1 | U1 | 74AHC374 | 74xx:74AHC374 |  | https://assets.nexperia.com/documents/data-sheet/74AHC_AHCT374.pdf
2 | 5 | U2, U3, U4, U8, U9 | 74LS32 | 74xx:74LS32 |  | http://www.ti.com/lit/gpn/sn74LS32
3 | 2 | U5, U6 | 74LS393 | 74xx:74LS393 |  | 74xx\74LS393.pdf
4 | 1 | U7 | 74LS08 | 74xx:74LS08 |  | http://www.ti.com/lit/gpn/sn74LS08
5 | 1 | U10 | 28C256 | Memory_EEPROM:28C256 |  | http://ww1.microchip.com/downloads/en/DeviceDoc/doc0006.pdf

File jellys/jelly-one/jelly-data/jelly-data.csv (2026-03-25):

Source: | /home/agsb/Projects/jelly-one/jelly-data/jelly-data.kicad_sch
Date: | qui 04 ago 2022 15:58:50
Tool: | Eeschema 6.0.4-6f826c9f35~116~ubuntu18.04.1
Generator: | /usr/share/kicad/plugins/bom_csv_grouped_by_value.py
Component Count: | 6
Individual Components:
Item | Qty | Reference(s) | Value | LibPart | Footprint | Datasheet
 |  | J1 | Conn_01x16_Female | Connector:Conn_01x16_Female |  | ~
 |  | U1 | 74AHC374 | 74xx:74AHC374 |  | https://assets.nexperia.com/documents/data-sheet/74AHC_AHCT374.pdf
 |  | U2 | 74AHC374 | 74xx:74AHC374 |  | https://assets.nexperia.com/documents/data-sheet/74AHC_AHCT374.pdf
 |  | U3 | 74LS83 | 74xx:74LS83 |  | http://www.ti.com/lit/gpn/sn74LS83
 |  | U4 | 74LS83 | 74xx:74LS83 |  | http://www.ti.com/lit/gpn/sn74LS83
 |  | U5 | 74HC00 | 74xx:74HC00 |  | http://www.ti.com/lit/gpn/sn74hc00
Collated Components:
Item | Qty | Reference(s) | Value | LibPart | Footprint | Datasheet
1 | 1 | J1 | Conn_01x16_Female | Connector:Conn_01x16_Female |  | ~
2 | 2 | U1, U2 | 74AHC374 | 74xx:74AHC374 |  | https://assets.nexperia.com/documents/data-sheet/74AHC_AHCT374.pdf
3 | 2 | U3, U4 | 74LS83 | 74xx:74LS83 |  | http://www.ti.com/lit/gpn/sn74LS83
4 | 1 | U5 | 74HC00 | 74xx:74HC00 |  | http://www.ti.com/lit/gpn/sn74hc00

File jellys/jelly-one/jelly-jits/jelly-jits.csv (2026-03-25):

Source: | /home/agsb/Projects/jelly-one/jelly-jits/jelly-jits.kicad_sch
Date: | qui 04 ago 2022 15:57:29
Tool: | Eeschema 6.0.4-6f826c9f35~116~ubuntu18.04.1
Generator: | /usr/share/kicad/plugins/bom_csv_grouped_by_value.py
Component Count: | 8
Individual Components:
Item | Qty | Reference(s) | Value | LibPart | Footprint | Datasheet
 |  | U1 | 74LS00 | 74xx:74LS00 |  | http://www.ti.com/lit/gpn/sn74ls00
 |  | U2 | 74LS273 | 74xx:74LS273 |  | http://www.ti.com/lit/gpn/sn74LS273
 |  | U3 | 74LS08 | 74xx:74LS08 |  | http://www.ti.com/lit/gpn/sn74LS08
 |  | U4 | 74LS273 | 74xx:74LS273 |  | http://www.ti.com/lit/gpn/sn74LS273
 |  | U5 | 74LS273 | 74xx:74LS273 |  | http://www.ti.com/lit/gpn/sn74LS273
 |  | U6 | 74LS00 | 74xx:74LS00 |  | http://www.ti.com/lit/gpn/sn74ls00
 |  | U7 | 74LS08 | 74xx:74LS08 |  | http://www.ti.com/lit/gpn/sn74LS08
 |  | U8 | 74LS273 | 74xx:74LS273 |  | http://www.ti.com/lit/gpn/sn74LS273
Collated Components:
Item | Qty | Reference(s) | Value | LibPart | Footprint | Datasheet
1 | 2 | U1, U6 | 74LS00 | 74xx:74LS00 |  | http://www.ti.com/lit/gpn/sn74ls00
2 | 4 | U2, U4, U5, U8 | 74LS273 | 74xx:74LS273 |  | http://www.ti.com/lit/gpn/sn74LS273
3 | 2 | U3, U7 | 74LS08 | 74xx:74LS08 |  | http://www.ti.com/lit/gpn/sn74LS08

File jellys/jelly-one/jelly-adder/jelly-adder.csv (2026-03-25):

Source: | /home/agsb/Projects/jelly-one/jelly-adder/jelly-adder.kicad_sch
Date: | sex 05 ago 2022 10:24:34
Tool: | Eeschema 6.0.4-6f826c9f35~116~ubuntu18.04.1
Generator: | /usr/share/kicad/plugins/bom_csv_grouped_by_value.py
Component Count: | 14
Individual Components:
Item | Qty | Reference(s) | Value | LibPart | Footprint | Datasheet
 |  | U1 | 74LS86 | 74xx:74LS86 |  | 74xx/74ls86.pdf
 |  | U2 | 74LS08 | 74xx:74LS08 |  | http://www.ti.com/lit/gpn/sn74LS08
 |  | U3 | 74LS32 | 74xx:74LS32 |  | http://www.ti.com/lit/gpn/sn74LS32
 |  | U4 | 74LS86 | 74xx:74LS86 |  | 74xx/74ls86.pdf
 |  | U5 | 74LS08 | 74xx:74LS08 |  | http://www.ti.com/lit/gpn/sn74LS08
 |  | U6 | 74LS86 | 74xx:74LS86 |  | 74xx/74ls86.pdf
 |  | U7 | 74LS08 | 74xx:74LS08 |  | http://www.ti.com/lit/gpn/sn74LS08
 |  | U8 | 74LS32 | 74xx:74LS32 |  | http://www.ti.com/lit/gpn/sn74LS32
 |  | U9 | 74LS86 | 74xx:74LS86 |  | 74xx/74ls86.pdf
 |  | U10 | 74LS08 | 74xx:74LS08 |  | http://www.ti.com/lit/gpn/sn74LS08
 |  | U11 | 74LS08 | 74xx:74LS08 |  | http://www.ti.com/lit/gpn/sn74LS08
 |  | U12 | 74LS08 | 74xx:74LS08 |  | http://www.ti.com/lit/gpn/sn74LS08
 |  | U13 | 74LS00 | 74xx:74LS00 |  | http://www.ti.com/lit/gpn/sn74ls00
 |  | U14 | 74LS32 | 74xx:74LS32 |  | http://www.ti.com/lit/gpn/sn74LS32
Collated Components:
Item | Qty | Reference(s) | Value | LibPart | Footprint | Datasheet
1 | 4 | U1, U4, U6, U9 | 74LS86 | 74xx:74LS86 |  | 74xx/74ls86.pdf
2 | 6 | U2, U5, U7, U10, U11, U12 | 74LS08 | 74xx:74LS08 |  | http://www.ti.com/lit/gpn/sn74LS08
3 | 3 | U3, U8, U14 | 74LS32 | 74xx:74LS32 |  | http://www.ti.com/lit/gpn/sn74LS32
4 | 1 | U13 | 74LS00 | 74xx:74LS00 |  | http://www.ti.com/lit/gpn/sn74ls00

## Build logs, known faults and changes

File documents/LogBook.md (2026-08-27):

# LogBook

### 26/08/2026

Maybe need change the 74HC393 to 74HC163.

Idea. Use REQ and ACK as XOR to pause and continue the clock before it goes to 393/163 chip
    
| REQ | ACK | CLK | action |
| --- | --- | --- | --- |
| 0 | 0 | flow | normal steps|
| 1 | 0 | stop | made a request to device|
| 1 | 1 | flow | device responds to request |
| 0 | 1 | stop | wait device ready for next |

### 01/08/2026

Review of Jelly, circuits and proposal changed. Chose use REQ and ACK protocol to talk with Non-Jelly world :)

Just a simple protocol: 

| REQ | ACK | action |
| --- | --- | --- |
| 0 | 0 | nothing |
| 1 | 0 | request |
| 1 | 1 | acknow |
| 0 | 1 | release |
| 0 | 0 | nothing |
| | | |

The Request and action depends on T0 T1 T2 T3

| T0 | T1 | T2 | T3 | action |
| --- | --- | --- | --- | --- |
| 0 | 0 | X | X | void internal | 
| 0 | 1 | X | X | data tape | 
| 1 | 0 | X | X | code tape | 
| 1 | 1 | X | X | standart I/O | 
| | | | |
| X | X | 0 | 0 | read | 
| X | X | 1 | 0 | write | 
| X | X | 0 | 1 | forward move | 
| X | X | 1 | 1 | backward move |
| | | | | 

### 12/09/2023

The draw of glue logics circuits, as complex, common and minimal, done. Not
finish, not tested, just scretch.

Replaced terms _begin_ and _again_ with _while_ and _until_ for clarify loop concepts.

### 06/09/2023

There are two extra circuits around Jelly, one for zero detector and one for reverse move.

The zero detector is usally done with gates OR, using a 74HC32 or diode logic. I must verify if could be done with red LEDS. See more later.

The reverse move is used because the unique diference in loops \[ (_begin_) and \] (_again_) is the direction of move. 

At _begin_ if data byte is zero then move forward to next code byte after matched _again_;  At _again_ if data byte is not zero then move backwards to next code byte after matched _begin_; 

A lot of duplicate code could be not used if a flag could hold a 'reverse' condition, as using a 74HC74 D-flip-flop. But why do this ? The 2k eeprom already have plenny unused space, so let's make it in software. Vide [logic loops](https://github.com/agsb/jelly/blob/main/documents/LogicLoop.md).

A simple pull-down array grants a clear byte (zero) for start counter of \[ and \] in loop mode. 

### 05/09/2023

Now, the core of Jelly is formed by 3 x AT28C16 eeproms (3 x 24 pins), 3 x 74HC574 latchs (3 x 20 pins), 1 x 74HC393 counter (1 x 14 pins), 1 x 74HC245 switch (1 x 14 pins), about 180/2 == 90 wirewrap lines. More connections for a 74HC74, a 74HC00, and clock circuit.

Jelly must wait for device ends the processing of a requisition. How about implement a send, wait, continue protocol ? Or a hardware handshake ?

The connector between Jelly and devices must have VCC, VSS, D0-D7, T0-T3, and two more lines for handshake. A line for signaling a request for device (REQ), and a line for acknowledge from device (ACK).  

### 24/08/2023

Laziness and the art of simplify. 

The core of Jelly is formed by 2 x AT28C16 eeproms (2 x 24 pins), 3 x 74HC574 latchs (3 x 20 pins), 1 x 74HC393 counter (1 x 14 pins), 1 x 74HC245 switch (1 x 14 pins), about 156/2 == 78 wirewrap lines. 

A 74HC74 dual D-flip-flop and 2 x 74HC32 OR for zero detector, about 28/2 == 14 wirewrap lines.

For state logics need more 4 x quad dual AND and 2 x quad dual NAND, uses about 98/2 == 49 lines of wirewrap.

But all state logics could be replaced by one more eeprom, 24/2 == 12 lines of wirewrap, and the OR detector by a array of diodes.

### 23/08/2023

Some tips for wirewraps. The wires color coded is:

  - Red – Positive Rail
  - Yellow – Negative rail
  - Green – common data bus 
  - Blue – direct between latch to eeprom
  - Orange – to leds
  - Black - to connector

### 18/08/2023

Reviews and reviews and reviews

Small typos and checkout counter

### 08/08/2023

_KISS_

Easy cut-off. 

Do simplify math operations just to 'decode, increase, decrease, copy'. 

Do a short-cut in 74HC393 counter from Q1d to CLR1, counting 0 to 7.

Do include the halt (!) in decoder.

**Jelly uses 1024 bytes for math, copy and decode, and less than 512 bytes for control and states, considering all  accessory logic equivalent to 512 bytes, can say that all Jelly is equivalent about 2048 x 8 d-flip-flops or about 65356 NANDS.**

### 03/08/2023

Made a simple program to make the eeprom contents as intel hex files, as code.hex and math.hex [romjelly](https://github.com/agsb/jelly/blob/main/sources/romjelly.c).

A trick, by use noop opcode to fetch code and move the code tape, each opcode just ends loading zero (noop).

When list down all steps for each opcodes, none are longer than 8 steps. 

The microcode could be done with 3 bits, A0-A2, and opcode with 4 bits, A3-A6, plus 2 bits for modes and pages, A7-A8, leaving A9-A10 for free.

### 01/08/2023

Jelly now have a stable version. No changes for the FSM/Math circuits and the glue logics is in 'reduce or delay' decision phase.

From wirewrap view, the connection of data output from 74HC574 into address input of AT28C16 is a mess, all lines crossed. What to do ?

The clear circuit, with resistors to ground (Vss) needs testing for values. 

### 26/07/2023

_be back to future_

Another revision of circuits.

Adopt a common notation for MSB at left and LSB at right. Must review the notes.

the zero dectector circuit, is necessary for resolve loop issues of _begin and again_.

the move reverse circuit, is necessary to necessary to avoid multiple copies of same code in eeprom.

the flip-flops, is still necessary to hold the move and mode lines state.

the internal implementation needs a clear and a copy math operations then no more reverse operation.

In the list of combinations used to control lines, state of devices and operations, the high nibble vary from 0x1 to 0xE, leaving 0x0 to do nothing and 0xF for select some extra states. 

with those extra states done by some glue logics, Jelly just needs one eeprom as finite state machine. 

Combining low nibble C0-C3 and high nibble T0-T3 as:

| signal | combines | gives |
| -- | -- | -- |
| select | T0 AND T1 AND T2 AND T3 | high when 0xF |
| U2.A8 | select AND C0 | address line of U2 |
| U2.A9 | select AND C1 | address line of U2 |
| U2.A10 | select AND C2 | address line of U2 |
| U6.CS | select AND C3 | chip select line of U6 |
| | | |
| control | NOT (select) | high when not 0xF |
| U4.CS | control AND C0 | chip select line of U4 |
| U5.CS | control AND C1 | chip select line of U5 |
| U6.OE | NOT (control AND C2) | output enable line of U6 |
| U7.OE | NOT (control AND C3) | output enable line of U7 |
| | | |
| toggle | NOT(C3) AND select | high when not in math | 
| U10.CLK1 | toggle AND C0 | toggles MOVE line |
| U10.CLK2 | toggle AND C1 | toggles MODE line |
| U10.CLR1 | toggle AND C2 | clear D-flip-flop |
| U10.CLR2 | toggle AND C2 | clear D-flip-flop |
| | | |
| zero | D0 OR D1 OR D2 OR D3 OR D4 OR D5 OR D6 OR D7 | high when not zero |
| | | |
| U1.A8 | zero | change page of FSM |
| U1.A9 | U10.Q1 | change page of FSM, loop mode |
| CN.T2 | T2 XOR (MOVE AND T3) | reverses movement forward or backward |
| | | |

BOM:
- CN is a dual eigth pins connector,
- U1 is a AT28C16, U2 is a AT28C16, 
- U4 is a 74HC574, U5 is a 74HC574, U6 is a 74HC574, 
- U7 is a 74HC245, U8 is a 74HC393, U10 is a 74HC74,
- U11 is a 74HC32, U12 is a 74HC32,
- U13 is a 74HC00, U14 is a 74HC00,
- U15 is a 74HC08, U16 is a 74HC08, U17 is a 74HC08, U18 is a 74HC08,
  
these extends the eeprom table of contents to toggle signals.

### 19/07/2023

Made a C small Jelly simulator for test the _begin and again_ loops using zero at A8 and mode at A9. Note, before mode loop from _again_, must backward code tape two times;

### 18/07/2023

_read the funny manuals_, again.

Take a time to review the documents to a version for release.

The wich pull-down resistor challenge starts. Must have resistors to ground (GND), for limit the draw current. 

For old 74HC-CMOS at 4.5-5.1 V, it must be ? Already known that Vil/Iil must be reference, almost all comments says, depends of manufacturer, source and circuit. I will try with a pool of 4k7 Ohms.

And for Leds ? At 4.5V, _20mA source limit_, and no more than 2mA per led, then 1.5k for Red (1.8V), 1.2k Yellow (2.2V), 750 for Green (3.1V) and 450 for Blue (3.6V);

### 16/07/2023

Thinking about mode normal and loop. 

Using zero detector circuit as A8 for FSM eeproms U1 and U2, solves how detect zero. 

When in page A8=0 if got a _begin_ [ is a end of loop. When in page A8=1 if got a _again_ [ is a loop back. Both cases sets the counter and select A9=1 for mode loop. Everthing else is same for both.

In mode loop, at A8=1 and A9=1, any _begin_ or _again_ just updates the counter until counter is zero. When then page will be, A8=0 and A9=1, which clears A8=0 and A9=0. 

As no data is read or writed, while in loop mode, the circuit for Math is used as counter.

Confirm use of two eeproms for Finite State Machine. One with M0-M3, for Math, decode (and maybe 3 flips-flops), and T0-T4 for control devices at connector; One for internal control lines and some not used and reserved.

The T0-T4 lines are multiplexed, maybe better one line for each (One, Two, forward, backward, read, write) ? Why not ? Because that mux T0-T3 are easy to decode by a MCU, keeps the connector small and any 74HC139 could demux if need.

### 11/07/2023

The 74HC273 is a weird circuit with a strange pinout and use it adds more two control lines for clear function.

The true-table for controls is done but too much logic ports to make it work.

Better return to original design, use 74HC574 and a pull-down pool for clear, and use another eeprom to control signals. Then Jelly will be pleny of lines for states and less glue logic.

### 03/07/2023

Jelly needs zero at counter for start counting \[ and \] inside loops, then I could try use a 74HC273 with clear as input latchs.

Some glue logics for define states for detect zero, toggle modes normal and loop, control chip signals need about more than 48 logic ports. Most from especific actions and decision true-tables.

### 01/07/2023

Jelly have 2 eeproms, and 16 data lines used as control and signals lines. What to do when need more ? Easy, use more one eeprom in paralel. 

With 11 address lines A0-A11, five lines A0-A4 for microcodes gives 32 steps, four lines A5-A8 for opcodes gives 16 codes, and two lines A9-A10 for 4 pages or modes. With 3 eeproms got 24 lines D0-D7, D8-D15, D16-D23.  

### 30/06/2023  

Start this logbook, as stack of changes in documentation of Jelly.

Changed the input latches to 74HC273, with clear. A pulse in clear line, clar the contents of latch. this could be used for get a zero to start loop counter (CL7) and to force a opcode noop at any moment (CL5). 

Remake of list with signals, controls, address and logic tables. 

Need more lines for begin and again and flags.

__A problem, too many lines for just two 8-bits eeproms__

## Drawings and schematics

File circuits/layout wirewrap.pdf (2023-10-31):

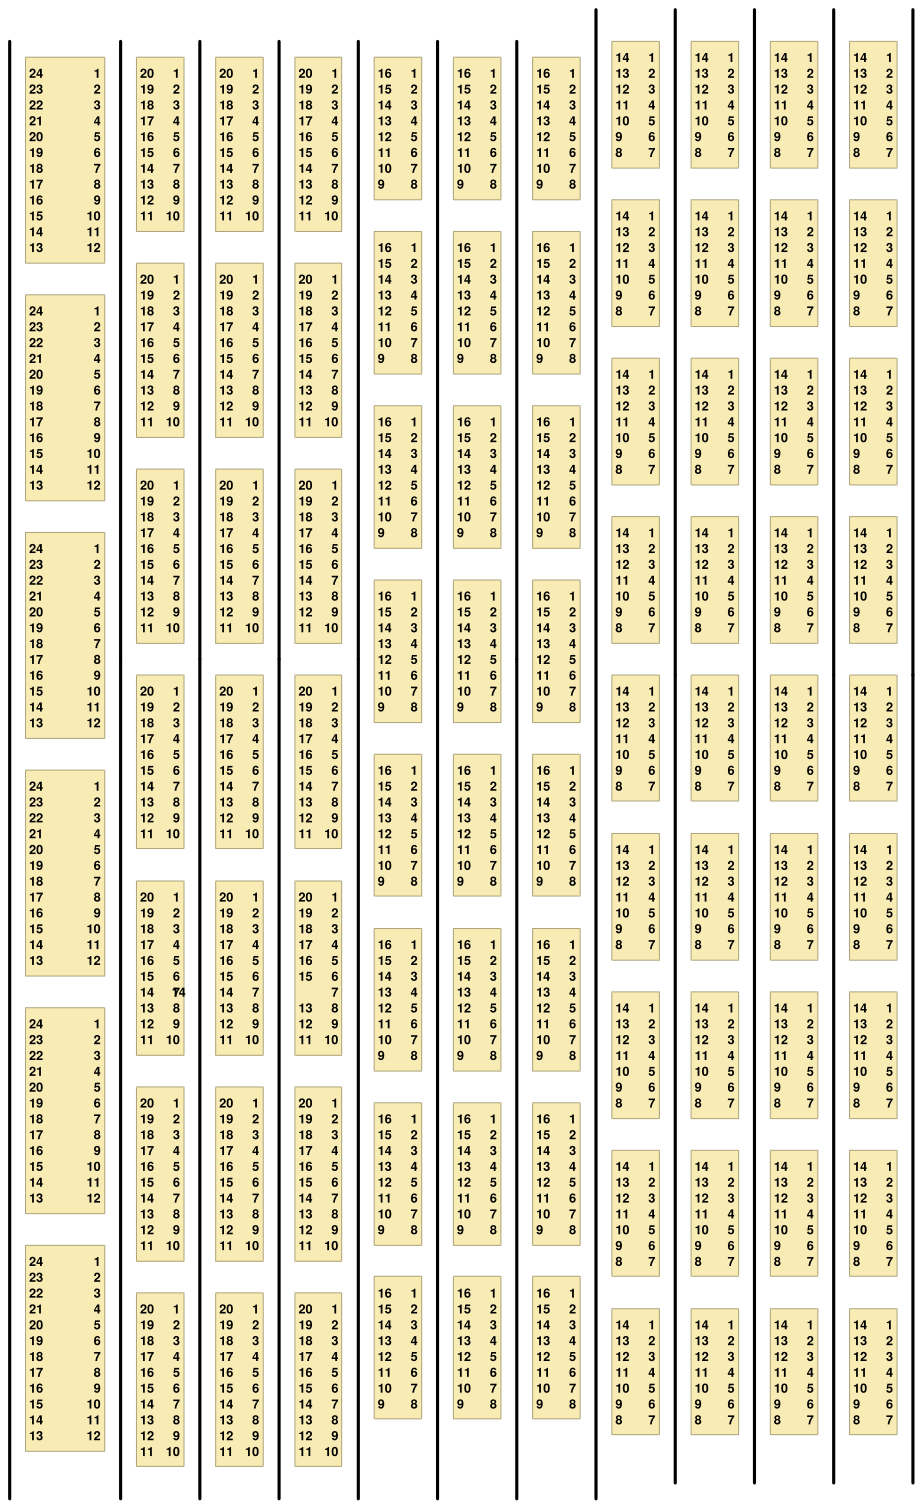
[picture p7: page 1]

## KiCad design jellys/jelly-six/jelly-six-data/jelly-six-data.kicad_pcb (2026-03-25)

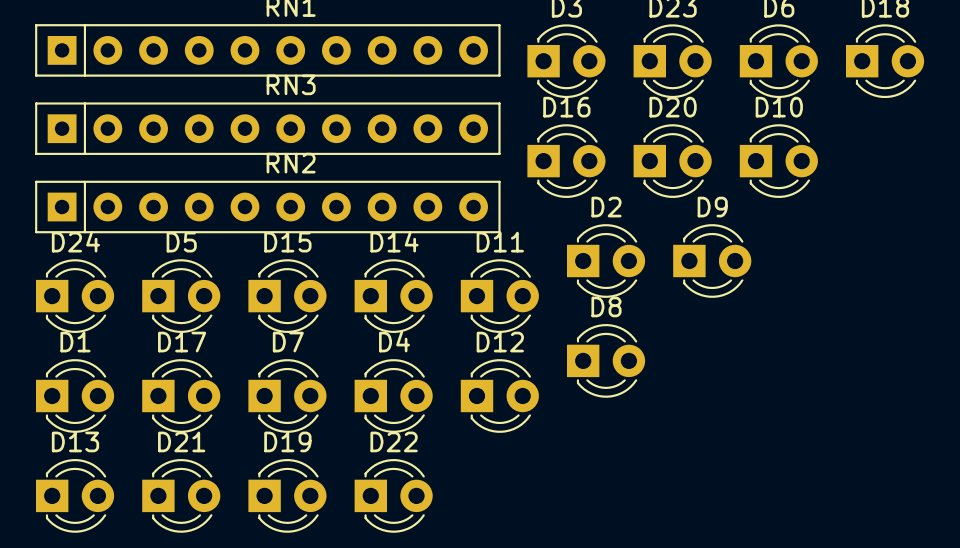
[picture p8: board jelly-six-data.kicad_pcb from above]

Board: 2 copper layers, 27 parts (0 on the bottom side), 25 nets, no tracks yet.

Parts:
D1, D2, D3, D4, D5, D6, D7, D8, D9, D10, D11, D12, D13, D14, D15, D16, D17, D18, D19, D20, D21, D22, D23, D24: TSAL4400; LED_D3.0mm_IRBlack
RN1, RN2, RN3: R_Network09_US; R_Array_SIP10

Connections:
/DR4: D1.2 (A), D13.2 (A), D14.2 (A), D15.2 (A), D16.2 (A)
unnamed: D1.1 (K), RN1.2 (R1)
unnamed: D2.1 (K), RN1.3 (R2)
unnamed: D3.1 (K), RN1.4 (R3)
unnamed: D4.1 (K), RN1.5 (R4)
unnamed: D5.1 (K), RN1.6 (R5)
unnamed: D6.1 (K), RN1.7 (R6)
unnamed: D7.1 (K), RN1.8 (R7)
unnamed: D8.1 (K), RN1.9 (R8)
unnamed: D9.1 (K), RN2.2 (R1)
unnamed: D10.1 (K), RN2.3 (R2)
unnamed: D11.1 (K), RN2.4 (R3)
unnamed: D12.1 (K), RN2.5 (R4)
unnamed: D13.1 (K), RN2.6 (R5)
unnamed: D14.1 (K), RN2.7 (R6)
unnamed: D15.1 (K), RN2.8 (R7)
unnamed: D16.1 (K), RN2.9 (R8)
unnamed: D17.1 (K), RN3.2 (R1)
unnamed: D18.1 (K), RN3.3 (R2)
unnamed: D19.1 (K), RN3.4 (R3)
unnamed: D20.1 (K), RN3.5 (R4)
unnamed: D21.1 (K), RN3.6 (R5)
unnamed: D22.1 (K), RN3.7 (R6)
unnamed: D23.1 (K), RN3.8 (R7)
unnamed: D24.1 (K), RN3.9 (R8)

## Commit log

2022-08-01 add circuits
2022-08-02 more circuits basic
2022-08-22 more test dig circuits
2022-08-30 new circuits
2022-08-31 more circuits
2022-09-15 update circuits six
2023-06-20 glue loop circuit test
2023-07-03 update circuits
2023-07-04 new circuit
2023-07-09 update circuits kicad
    [jelly.kicad_pcb, jelly.kicad_sch]
2023-08-08 Update CircuitDesign.md
    tests of connector design
2023-08-23 adds diylc squemas for wire wrap
2023-08-26 Create WireWrapMap
2023-08-26 Update WireWrapMap
2023-08-26 wirewrap lists
2023-08-27 wirewrap maps
2023-09-08 Update LogicLoop.md
    some circuit updates
2026-03-22 Review for make it
    [jelly.kicad_pcb, jelly.kicad_sch]
2026-03-25 review and preserve old files
    [code sheet.kicad_sch, jelly-adder.csv, jelly-adder.kicad_pcb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]
2026-07-20 review of docs
    [jelly-adder.csv, jelly-adder.kicad_pcb, jelly-adder.kicad_sch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]
2026-08-05 more reviews for minimal jelly
    [code sheet.kicad_sch, jelly-adder.csv, jelly-adder.kicad_pcb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]
2026-08-18 review circuits
